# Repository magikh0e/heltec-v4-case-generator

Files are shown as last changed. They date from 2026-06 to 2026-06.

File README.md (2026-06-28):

# Heltec WiFi LoRa 32 (V4) Case Generator

A parametric OpenSCAD enclosure for the **Heltec WiFi LoRa 32 V4** (ESP32-S3 + SX1262, with an on-board OLED). Same two-part snap+screw architecture as the [WisBlock case](https://github.com/magikh0e/wisblock-case-generator), but laid out for the V4's board size and its connector row.

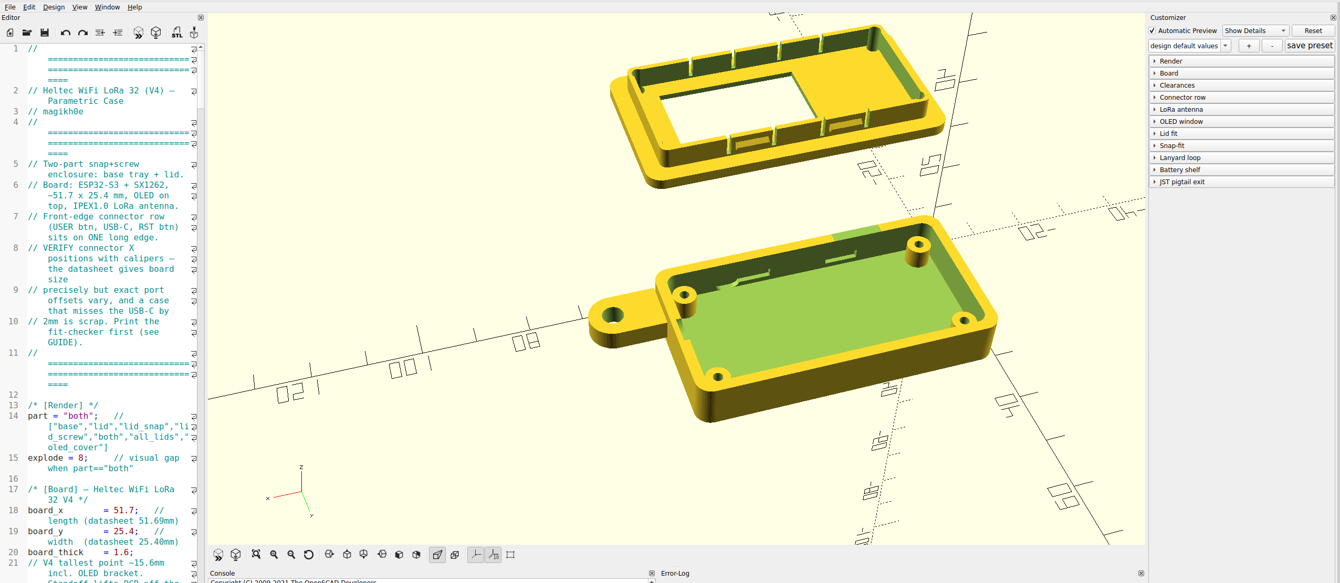
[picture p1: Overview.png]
The default Heltec V4 case in OpenSCAD: base tray and lid with the OLED window, in the exploded "both" preview, with the Customizer panel exposing every adjustable group


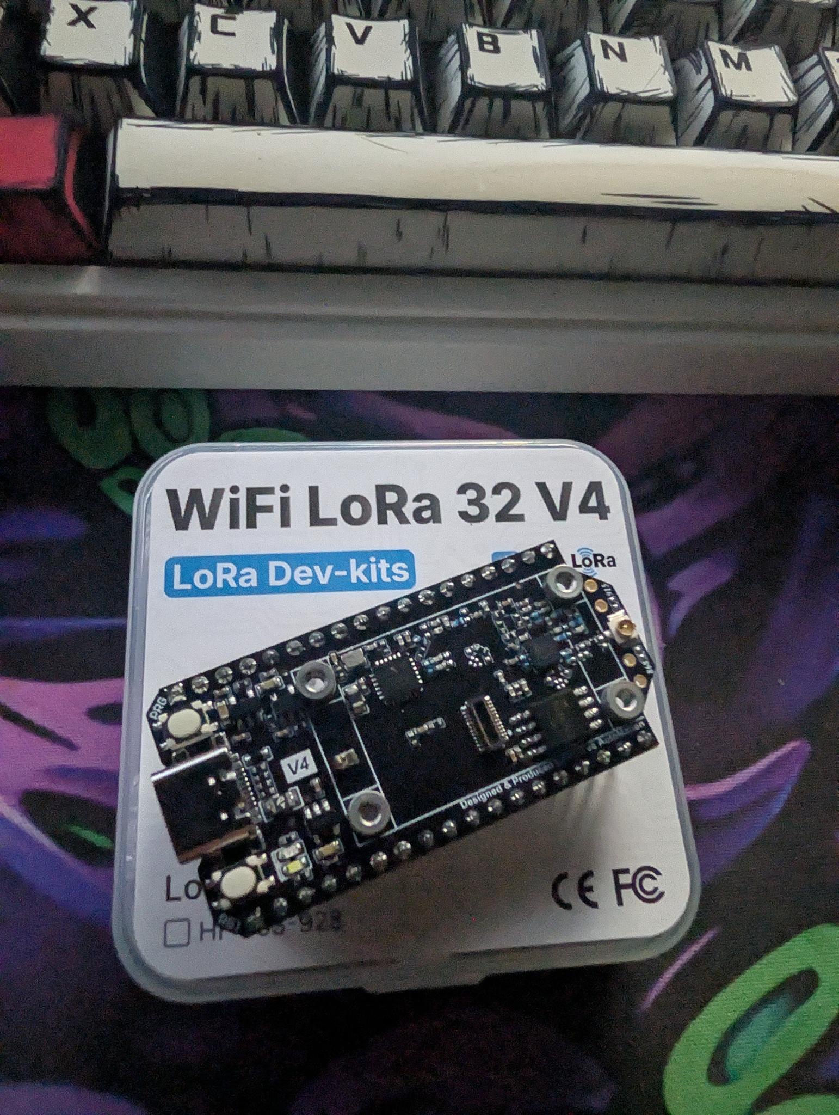
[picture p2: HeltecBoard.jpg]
A Heltec WiFi LoRa 32 V4 board — the hardware this case is built for


*The board it's built for: a Heltec WiFi LoRa 32 V4 (ESP32-S3 + SX1262).*

**Source / latest version:** https://github.com/magikh0e/heltec-v4-case-generator

**Also on Cults3D:** https://cults3d.com/en/users/magikh0e/3d-models

> Dimensions come from the published V4 product manual and the geometry is verified manifold, but port offsets vary and tolerances differ by printer. The connector row is the high-risk area, so always run the fit-checker (section 5) before a full print.

---

## How the V4 differs from the WisBlock case

If you've used the WisBlock generator, the structure is identical. Only the board-specific bits changed:

- **Smaller board:** 51.7 x 25.4 mm (vs 60 x 30).
- **Connector row on one LONG edge:** the V4 puts the USER button, USB-C, and RST button in a row along the same long side. The generator cuts them at individual X positions on that edge (`front_edge`, default `y0`).
- **OLED window:** the V4 has a 0.96" display on top. The lid has an optional cutout (`oled_window`) with a recessed ledge for a clear cover.
- **LoRa antenna:** IPEX1.0 on board. Default is an **SMA bulkhead hole** (`ant_mode="sma"`) so you run a u.FL to SMA pigtail out to a real antenna for best range. Switch to `ant_mode="internal"` for no hole (keep the antenna inside).
- **M2 mounting** (the V4 uses M2, vs M2.5 on the WisBlock).

---

## 1. What you need

- **OpenSCAD**: https://openscad.org
- The file **`Heltecv4_Case_Generator.scad`**.
- A slicer (PrusaSlicer, Orca, Cura, Bambu Studio...).
- **Calipers**: more important here than on the WisBlock, because the connector X positions are the make-or-break dimension (see section 5).

This repo ships the generator plus pre-exported, ready-to-slice STLs: `heltec_v4_base.stl`, `heltec_v4_lid_snap.stl`, `heltec_v4_lid_screw.stl`, `heltec_v4_both_lids.stl`, and the clear `heltec_v4_oled_cover.stl` (print that one in transparent filament). The STLs are built from the default variables; if you change board-specific dimensions, re-export from the `.scad` (section 4) so the parts match.

---

## 2. Opening and previewing

1. Open `Heltecv4_Case_Generator.scad` in OpenSCAD.
2. **F5** = fast preview, **F6** = full render.
3. Enable the **Customizer** (Window menu) for labelled sliders and toggles grouped under `[Board]`, `[Connector row]`, `[OLED window]`, etc.
4. Export with **File -> Export -> Export as STL** (`F7`).

---

## 3. Choosing what to render

```
part = "both";
```

| Value | Renders |
|---|---|
| `"base"` | Base tray only |
| `"lid"` | Lid following `use_snaps` / `use_screws` |
| `"lid_snap"` | Lid, snaps only |
| `"lid_screw"` | Lid, screw holes only |
| `"all_lids"` | Both lids side by side on one plate |
| `"oled_cover"` | Printable clear window cover (print in transparent filament) |
| `"both"` | Base + lid exploded. **Preview only, don't print this** |

The **base is shared** by both lids (it has snap recesses *and* screw posts). Print one base, then whichever lid you want.

---

## 4. Print workflow

1. `part = "base";` -> F6 -> export base.
2. `part = "lid_snap";` (or `lid_screw`) -> F6 -> export lid.
3. Slice both. Base flat / open side up, lid lip-up, no supports needed (the snap chamfers stay under ~45 degrees). The OLED window prints fine face-up.
4. Assemble (section 8).

---

## 5. Verify before printing — the connector row

This is the critical step for the V4. The board size is exact, but the **X positions of the USB-C and buttons along the front edge** must match your board or the ports won't line up. Measure from the left end of the PCB to the center of each feature and set:

```
usbc_x    = 14;   // USB-C center
usrbtn_x  = 6;    // USER button center (0 disables)
rstbtn_x  = 22;   // RST button center  (0 disables)
```

Also confirm:
- `front_edge` (`y0` or `y1`): which long side the row faces. If your board sits flipped, set `y1`.
- `oled_cx` / `oled_cy`: the OLED window center, if you've enabled it.
- `usbc_w` / `usbc_h`: widen for a chunky cable overmold.

**Fit-checker trick:** set `comp_clear = 1;` and print just the base. You get a shallow tray that confirms the board footprint, USB-C, and button alignment in about 15 minutes of filament. Adjust the X values, reprint if needed, then set `comp_clear` back to 12 for the real thing.

---

## 6. Variable reference

### `[Board]`
| Variable | Default | Meaning |
|---|---|---|
| `board_x`, `board_y` | 51.7, 25.4 | V4 PCB footprint (mm). |
| `standoff_h` | 4 | PCB lift off the floor. |
| `screw_hole_d` | 1.8 | M2 self-tap pilot. |
| `post_d` | 4.5 | Standoff post OD. |
| `hole_inset_x/y` | 2.5 | Mounting-hole inset. Verify. |

### `[Clearances]`
| Variable | Default | Meaning |
|---|---|---|
| `wall`, `floor_t`, `lid_t` | 2.0 | Thicknesses. |
| `clr` | 0.4 | Gap around PCB. |
| `comp_clear` | 12 | Headroom above PCB (the OLED bracket is the tall part). |

### `[Connector row]`
| Variable | Default | Meaning |
|---|---|---|
| `front_edge` | `"y0"` | Which long edge the row faces. |
| `usbc_x` | 14 | USB-C center X. **Verify**. |
| `usbc_w`, `usbc_h` | 9.5, 4.0 | USB-C opening size. |
| `usbc_z` | 1.0 | Port bottom above PCB surface. |
| `usrbtn_x` | 6 | USER button X (0 = off). |
| `rstbtn_x` | 22 | RST button X (0 = off). |
| `btn_d` | 3.5 | Button pin-poke hole diameter. |

### `[LoRa antenna]`
| Variable | Default | Meaning |
|---|---|---|
| `ant_mode` | `"sma"` | `"sma"` = bulkhead hole; `"internal"` = no hole. |
| `ant_d` | 6.5 | SMA nut hole diameter. |
| `ant_edge` | `"x1"` | Which short wall the SMA exits. |
| `ant_pos` | board_y/2 | Position along that wall. |
| `ant_z` | 3 | Hole-center height above PCB. |

> Note: for the SMA pigtail to work you may need to move the V4's RF-path resistor to the IPEX side per Heltec's hardware notes. Check the board docs before relying on the external antenna.

### `[OLED window]`
| Variable | Default | Meaning |
|---|---|---|
| `oled_window` | true | true = cutout; false = solid lid. |
| `oled_w`, `oled_h` | 26, 15 | Window size. Verify against your screen. |
| `oled_cx`, `oled_cy` | 33, center | Window center on the board. |
| `oled_recess` | true | Recessed ledge for a clear cover. |
| `oled_ledge` | 1.5 | Ledge width the cover rests on. |
| `oled_cover_t` | 1.0 | Recess depth (match your acrylic thickness). |
| `oled_cover_gap` | 0.3 | Fit clearance for the printed cover to drop in. |

A clear cover is optional. Two ways to make one:
- **Print it:** set `part = "oled_cover";` and print in transparent PETG or clear PLA (or use the bundled `heltec_v4_oled_cover.stl`). It's sized to drop straight into the recess (footprint minus `oled_cover_gap`).
- **Cut it:** a 1 mm acrylic / polycarbonate rectangle at `oled_w + 2*oled_ledge` x `oled_h + 2*oled_ledge` (about 28.7 x 17.7 mm at defaults).

Or just leave the window open for a bare cutout.

### `[Lid fit]`
| Variable | Default | Meaning |
|---|---|---|
| `use_screws` | true | M2 holes into the corner posts. |
| `use_snaps` | true | Cantilever snaps on the long walls. |

Both on by default (snaps hold it shut, screws clamp for weather sealing).

### `[Snap-fit]`
Same as the WisBlock: `snap_depth` (0.9) is the click strength. Lower for easier opening, higher for a firmer lock. Keep `snap_relief = true` for PLA/PETG.

### `[Lanyard]`, `[Battery shelf]`, `[JST pigtail exit]`
- Lanyard tab defaults to the `x1` short end. **If your SMA is also on `x1`, move one of them** (`lanyard_edge` or `ant_edge`) so they don't overlap.
- Battery shelf off by default; enable and size it for your LiPo.
- Pigtail slot (`pigtail_slot`) lets the SH1.25 battery / solar leads exit; set `pigtail_x` along the front edge.

---

## 7. Quick recipes

**Headless node, no screen:** `oled_window = false;`

**Keep antenna internal:** `ant_mode = "internal";`

**Board mounted the other way round:** `front_edge = "y1";` (and move the OLED / pigtail edges to match).

**Tighter fit:** `clr = 0.3;`. Won't seat: `clr = 0.5;`.

**Big battery in the lid space:** enable `battery`, set `bat_x` / `bat_y`, and raise `comp_clear` if it's thick.

---

## 8. Assembly

1. Seat the V4 on the four standoffs (M2 corners).
2. **SMA build:** mount the u.FL to SMA pigtail's bulkhead through the antenna hole, tighten the nut, then clip the u.FL onto the board's IPEX1.0 connector. **Internal build:** just leave the IPEX antenna inside.
3. If using a battery, route its SH1.25 lead out through the pigtail slot.
4. Optional: drop a clear cover into the OLED recess (print `part="oled_cover"` in transparent filament, use the bundled STL, or cut acrylic to size). A dab of clear glue holds it.
5. Close the lid: snap it shut, then drive four **M2 x 6 to 8 mm** self-tapping screws into the posts (or use M2 heat-set inserts + machine screws if you'll open it often).

---

## 9. Material notes (outdoor / hot climates)

- **PLA**: easiest, but softens in heat and sun, so the snaps relax over time. Indoor / bench only.
- **PETG**: best all-round here; flexes for repeated snaps, better heat and UV tolerance.
- **ASA**: best for sustained outdoor sun.

For a sealed outdoor node, use the screw lid (optionally with a gasket) and PETG or ASA.

---

## 10. Disclaimer

Dimensions come from the published V4 product manual and the geometry is verified manifold, but **port offsets vary and tolerances differ by printer**. The connector row is the high-risk area: always run the fit-checker (section 5) before a full print.

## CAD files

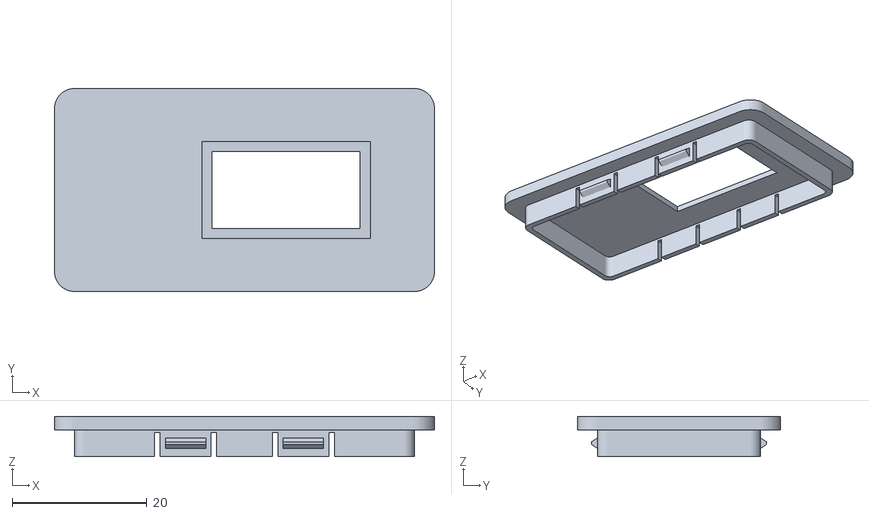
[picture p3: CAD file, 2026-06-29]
stls/heltec_v4_lid_snap.stl
56.5 x 30.2 x 6.00

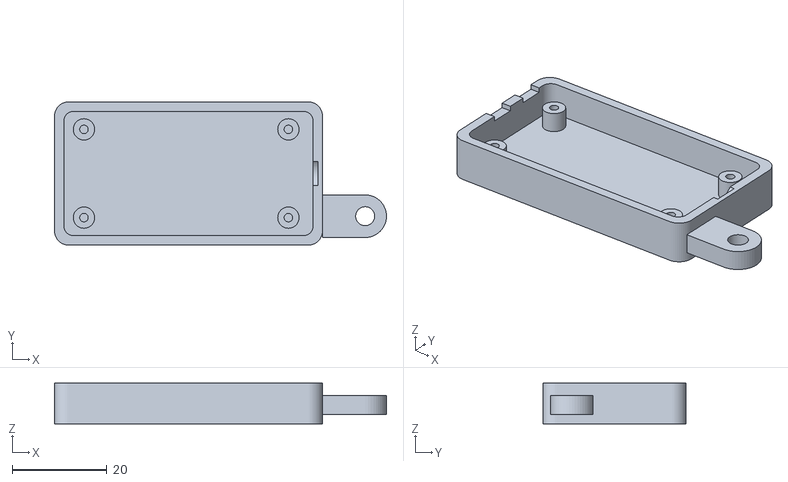
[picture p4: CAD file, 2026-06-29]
stls/heltec_v4_base.stl
70.0 x 30.2 x 8.60

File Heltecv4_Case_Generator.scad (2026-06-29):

// ============================================================
// Heltec WiFi LoRa 32 (V4) — Parametric Case
// magikh0e
// ============================================================
// Two-part snap+screw enclosure: base tray + lid.
// Board: ESP32-S3 + SX1262, ~51.7 x 25.4 mm, OLED on top, IPEX1.0 LoRa antenna.
// Front-edge connector row (USER btn, USB-C, RST btn) sits on ONE long edge.
// VERIFY connector X positions with calipers — the datasheet gives board size
// precisely but exact port offsets vary, and a case that misses the USB-C by
// 2mm is scrap. Print the fit-checker first (see GUIDE).
// ============================================================

/* [Render] */
part = "both";   // ["base","lid","lid_snap","lid_screw","both","all_lids","oled_cover"]
explode = 8;     // visual gap when part=="both"

/* [Board] — Heltec WiFi LoRa 32 V4 (verified against V4.2 dimensional drawing) */
board_x        = 51.7;   // length (datasheet 51.69mm)
board_y        = 25.4;   // width  (datasheet 25.40mm)
board_thick    = 1.6;
// V4 component stack is 10.70mm above the PCB (datasheet + side-view drawing).
standoff_h     = 4;

// M2 mounting holes — measured hole-to-hole spans (confirmed against the board):
//   along the 51.69 length: 33.00mm hole-to-hole (centered)
//   across the 25.40 width:  18.60mm hole-to-hole
hole_span_x    = 33.00;  // hole-to-hole along board length
hole_span_y    = 14.00;  // hole-to-hole across board width (datasheet p16)
screw_hole_d   = 1.8;    // M2 self-tap pilot in plastic
post_d         = 4.5;    // standoff post OD (M2)

/* [Clearances] */
wall           = 2.0;
floor_t        = 2.0;
lid_t          = 2.0;
clr            = 0.4;    // gap around PCB
// Headroom above PCB. Real V4 stack (incl. OLED) is 10.70mm; +margin.
comp_clear     = 11.5;

/* [Connector row] — all along one LONG edge (the "front") */
/* [Connectors] — from the V4.2 drawing, USB-C + JSTs are on a SHORT end */
// USB-C sits on a short end of the board. usbc_pos locates it across the width (board_y),
// usbc_z is the connector CENTER height above the PCB top (side-view drawing: ~5.5mm).
conn_edge      = "x0";        // ["x0","x1"] which short end the connectors face
usbc_pos       = board_y/2 + 3.1;  // across-width position (drawing: 15.81 from edge -> +3.1 off center)
usbc_w         = 9.5;         // opening width
usbc_h         = 3.5;         // opening height (V4 USB-C ~3.2 + margin)
usbc_z         = 5.5;         // USB-C connector CENTER height above PCB top (side view)

// Two SH1.25 JSTs on the same short end, near the USB-C.
jst_enable     = true;
jst_w          = 5.0;         // JST lead slot width
jst_h          = 4.0;         // JST lead slot height
jst1_pos       = board_y/2 - 1.5;  // solar JST across-width position
jst2_pos       = board_y/2 + 7.5;  // battery JST
jst_z          = 2.0;         // JST lead height above PCB

// Buttons (USER/RST) also on this short end — poke holes, optional.
btn_d          = 3.5;         // pin-poke hole for the buttons (0 to disable)
btn1_pos       = board_y/2 - 7;
btn2_pos       = board_y/2 + 7;

/* [LoRa antenna] */
// V4 LoRa antenna is IPEX1.0. Default: SMA bulkhead hole so you run a u.FL->SMA
// pigtail out to a real antenna (best for range). Option: internal IPEX, no hole.
ant_mode       = "sma";       // ["sma","internal"]
ant_d          = 6.5;         // SMA bulkhead nut hole (~6.3-6.5mm)
ant_edge       = "x1";        // which wall the SMA exits (short end)
ant_pos        = board_y/2;   // position along that edge
ant_z          = 3;           // height of hole center above PCB top

/* [OLED window] */
// V4 0.96" OLED, active area 22.00 x 11.40mm (from the V4.2 drawing). Toggle a lid window.
oled_window    = true;        // true = cutout to see screen; false = solid lid
oled_w         = 22.0;        // window width  (X, along board length)
oled_h         = 11.4;        // window height (Y, across board width)
oled_cx        = board_x*0.62; // window center X (OLED sits toward the non-USB end) — VERIFY
oled_cy        = board_y/2;   // window center Y
oled_recess    = true;        // sink a ledge so a clear cover sits flush
oled_ledge     = 1.5;         // ledge width around the window for the cover to rest on
oled_cover_t   = 1.0;         // recess depth for the cover
oled_cover_gap = 0.3;         // fit clearance so the printed cover drops into the recess

/* [Lid fit] */
use_screws     = true;
use_snaps      = true;
lip_h          = 4;
lip_inset      = wall/2;
vent           = true;
vent_count     = 4;

/* [Snap-fit] (when use_snaps) — on the two LONG walls */
snap_count     = 2;
snap_w         = 6;
snap_depth     = 0.9;
snap_h         = 1.6;
snap_z         = 2.0;
snap_lead      = 0.6;
snap_relief    = true;

/* [Lanyard loop] */
lanyard        = true;
lanyard_edge   = "x1";        // short end; if SMA also on x1, move one of them
lanyard_pos    = 0.5;
lanyard_thick  = 4;
lanyard_reach  = 9;
lanyard_hole_d = 4;

/* [Battery shelf] */
battery        = false;
bat_x          = 50;
bat_y          = 30;
bat_wall       = 1.5;
bat_pos_x      = 1;
bat_pos_y      = 1;

/* [JST pigtail exit] */
// Slot for the SH1.25 battery / solar leads to exit. On the connector edge.
pigtail_slot   = true;
pigtail_w      = 5;
pigtail_h      = 3;
pigtail_edge   = "y0";
pigtail_x      = 40;          // X position along the long edge
pigtail_z      = 0;

// ============================================================
// derived
// ============================================================
inner_x = board_x + 2*clr;
inner_y = board_y + 2*clr;
inner_z = standoff_h + board_thick + comp_clear;

out_x = inner_x + 2*wall;
out_y = inner_y + 2*wall;
base_z = floor_t + standoff_h + board_thick + 1;
lid_z  = inner_z - standoff_h - board_thick + lid_t;

eps = 0.01;
$fn = 48;

// M2 hole positions: centered rectangle, 33.00 x 18.60 hole-to-hole.
// In PCB coordinates [0..board_x] x [0..board_y]; clr offsets into the cavity.
hcx = clr + board_x/2;
hcy = clr + board_y/2;
hxa = hcx + hole_span_x/2;   // +x column
hxb = hcx - hole_span_x/2;   // -x column
hy_hi = hcy + hole_span_y/2;
hy_lo = hcy - hole_span_y/2;
holes = [[hxb,hy_lo],[hxa,hy_lo],[hxb,hy_hi],[hxa,hy_hi]];

// ============================================================
// primitives
// ============================================================
module rrect(x,y,z,r=2){
    linear_extrude(z) offset(r) offset(-r) square([x,y]);
}
module post(h){
    difference(){
        cylinder(d=post_d, h=h);
        translate([0,0,-eps]) cylinder(d=screw_hole_d, h=h+2*eps);
    }
}

// rectangular port cut through a LONG wall (y0/y1), centered at board-X = cx
module port_cut_long(edge, cx, w, h, z_above_pcb){
    zc = floor_t + standoff_h + board_thick + z_above_pcb;
    xc = wall + clr + cx;
    if(edge=="y0") translate([xc - w/2, -eps, zc]) cube([w, wall+2*eps, h]);
    if(edge=="y1") translate([xc - w/2, out_y-wall-eps, zc]) cube([w, wall+2*eps, h]);
}
// round hole through a LONG wall
module hole_cut_long(edge, cx, d, z_above_pcb){
    zc = floor_t + standoff_h + board_thick + z_above_pcb;
    xc = wall + clr + cx;
    if(edge=="y0") translate([xc, wall+eps, zc]) rotate([90,0,0]) cylinder(d=d, h=wall+2*eps, center=true);
    if(edge=="y1") translate([xc, out_y-wall-eps, zc]) rotate([-90,0,0]) cylinder(d=d, h=wall+2*eps, center=true);
}
// rectangular port cut through a SHORT wall (x0/x1), centered at board-Y = cy
module port_cut_short(edge, cy, w, h, z_above_pcb){
    zc = floor_t + standoff_h + board_thick + z_above_pcb;
    yc = wall + clr + cy;
    if(edge=="x0") translate([-eps, yc - w/2, zc]) cube([wall+2*eps, w, h]);
    if(edge=="x1") translate([out_x-wall-eps, yc - w/2, zc]) cube([wall+2*eps, w, h]);
}
// round hole through a SHORT wall (x0/x1)
module hole_cut_short(edge, cy, d, z_above_pcb){
    zc = floor_t + standoff_h + board_thick + z_above_pcb;
    yc = wall + clr + cy;
    if(edge=="x0") translate([wall+eps, yc, zc]) rotate([0,-90,0]) cylinder(d=d, h=wall+2*eps, center=true);
    if(edge=="x1") translate([out_x-wall-eps, yc, zc]) rotate([0,90,0]) cylinder(d=d, h=wall+2*eps, center=true);
}

// rounded-end slot primitive (along X, pierces Y)
module _slotx(w,h){
    hull(){
        translate([-w/2 + h/2, 0, 0]) rotate([90,0,0]) cylinder(d=h, h=wall+2*eps, center=true);
        translate([ w/2 - h/2, 0, 0]) rotate([90,0,0]) cylinder(d=h, h=wall+2*eps, center=true);
    }
}
module pigtail_cut(){
    if(pigtail_slot){
        xc = wall + clr + pigtail_x;
        zb = floor_t + pigtail_z + pigtail_h/2;
        if(pigtail_edge=="y0") translate([xc, wall+eps, zb]) _slotx(pigtail_w,pigtail_h);
        if(pigtail_edge=="y1") translate([xc, out_y-wall-eps, zb]) _slotx(pigtail_w,pigtail_h);
    }
}
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

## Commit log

2026-06-28 Initial commit: parametric Heltec WiFi LoRa 32 (V4) case generator
    Parametric OpenSCAD enclosure for the Heltec WiFi LoRa 32 V4 (ESP32-S3
    + SX1262, on-board OLED). Base tray + snap/screw lids, optional OLED
    window, SMA antenna hole, M2 mounting. Ships with pre-exported,
    print-ready STLs and a README guide.
    [Heltecv4_Case_Generator.scad, heltec_v4_base.stl, heltec_v4_both_lids.stl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]
2026-06-28 Add model overview image; firm up STL wording in README
    [heltec_v4_base.stl, heltec_v4_both_lids.stl, heltec_v4_lid_screw.stl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]
2026-06-28 Add photo of the actual Heltec WiFi LoRa 32 V4 board
    The board the case is dimensioned for.
2026-06-28 Normalize STL folder to lowercase stls/
    Match the WisBlock repo's lowercase stls/ convention.
    [heltec_v4_base.stl, heltec_v4_both_lids.stl, heltec_v4_lid_screw.stl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]
2026-06-29 Relayout V4 case against the V4.2 dimensional drawing
    - Move the connector cutouts from a long edge to a short end
    (conn_edge="x0"): USB-C + JST slots now exit the short end.
    - Remeasure the four M2 mounting holes to the real asymmetric
    positions (hole_end_a/b + hole_span_y) instead of a symmetric inset.
    - Resize/reposition the OLED window (22 x 11.4, toward the non-USB end).
    - Add JST battery/solar lead slots; reposition the buttons; tune
    comp_clear and USB-C height for the side-view geometry.
    - Re-export base + lid_snap STLs; drop the other STL exports for now.
    [Heltecv4_Case_Generator.scad, heltec_v4_base.stl, heltec_v4_both_lids.stl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]
